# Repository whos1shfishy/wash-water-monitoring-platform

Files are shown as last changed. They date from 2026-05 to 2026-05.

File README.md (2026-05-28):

## Overview
Blastoise is a modular real-time water quality monitoring platform designed to monitor, flag, and improve water conditions in WASH-related environments. Our prototype combines embedded sensing, wireless communication, and a live dashboard to provide early warning and scalable deployment.

## Problem
Unsafe water, sanitation, and hygiene systems continue to affect billions globally. Existing monitoring approaches are often manual, delayed, sparse, or too expensive for persistent deployment.

## Our Solution
We developed a minimum viable product that:
- Measures water quality in real time
- Sends readings from embedded hardware to a dashboard
- Supports future multi-node expansion using ESP32 + LoRa architecture
- Can integrate modular treatment pods and future sensor upgrades

## Key Features
- Real-time water monitoring
- Modular pod-based hardware
- ESP32-based embedded system
- LoRa-ready scalable node architecture
- Dashboard for visualization and alerts
- Future-ready sensor expansion

## System Architecture
Our system is built as a modular, node-based architecture with five main layers:

Sensor layer – Each pod contains water-quality sensors (e.g., turbidity and temperature in the MVP, with provision for additional probes such as pH, dissolved oxygen, ORP, and EC/TDS in future iterations). These sensors are mounted in direct contact with the water stream and provide continuous measurements to the controller.

Controller layer – An ESP32 microcontroller reads the sensor data, performs basic signal processing and threshold checks, and drives both the communication module and local indicators (LCD, status LEDs, and any onboard alerts). It also controls actuation elements such as the pump or valves for treatment stages.

Communication layer – Each node is designed to connect via a low-power long‑range wireless link (e.g., LoRa) to a central gateway. The controller packages sensor readings and health metrics (battery level, RSSI, uptime) into messages that are sent periodically or when thresholds are exceeded.

Power layer – The hardware is powered by a small battery and optional solar panel. A power-management stage (charging and regulation) supplies stable rails to the ESP32, sensors, communication module, and pump, while monitoring consumption to support longer-term deployment.

Treatment and actuation layer – The pod incorporates a small pump and filter/treatment cartridge. Based on sensor readings or configured rules, the controller can activate the pump to circulate water through the cartridge, enabling basic treatment now and providing a modular interface for future treatment pods (e.g., carbon filters, UV-LED units, or advanced media).

Multiple nodes can be deployed across a pond, tank, or network of water bodies. Each node sends data to a gateway, which forwards it to a dashboard for real-time visualization, alerting, and future analytics. This architecture lets the system scale from a single prototype to a distributed fleet of monitoring and treatment pods while keeping each node simple and modular.

Sensor Node -> ESP32 -> LoRa / Communication Layer -> Gateway / Dashboard  
Optional treatment path: Sensor trigger -> Pump control -> Filter / treatment pod

## Hardware
- ESP32
- [Turbidity sensor]
- [Temperature sensor]
- LCD screen
- Status LED
- Pump / motor
- Tubing and filter pod
- Battery / power system
- 3D printed enclosure

## Software
- Arduino / ESP32 firmware
- Dashboard / frontend
- Data visualization interface
- Alert / threshold logic

## Verification
Technical verification files are available in the `/verification` folder and include:
- Calculations
- Calibration data
- CAD files
- Wiring diagrams
- Test images and validation notes

## Demo
Dashboard / UX link:(https://rainbow-hydro-metric-flow.base44.app/?is_new_user=true)

## Repository Structure
- `firmware/` - embedded code
- `dashboard/` - dashboard notes and screenshots
- `electronics/` - wiring and BOM
- `cad/` - CAD files and renders
- `verification/` - calculations, validation, testing
- `slides/` - final presentation

## Team
- Ishmam Jawad Karim

## Acknowledgements
This project may incorporate open-source tools, external references, and AI-assisted workflows. All external work is acknowledged and used in accordance with academic integrity expectations.

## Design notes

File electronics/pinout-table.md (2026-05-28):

# ESP32 Pinout — Blastoise Node

| GPIO | Function | Direction |
|---|---|---|
| 2 | LoRa DIO0 | Input |
| 4 | DS18B20 OneWire | I/O |
| 5 | LoRa NSS | Output |
| 14 | LoRa RESET | Output |
| 18 | SPI SCK | Output |
| 19 | SPI MISO | Input |
| 21 | I2C SDA | I/O |
| 22 | I2C SCL | Output |
| 23 | SPI MOSI | Output |
| 25 | LED Red | Output |
| 26 | Relay (pump) | Output |
| 27 | LED Green | Output |
| 32 | LED Blue | Output |
| 34 | Turbidity ADC | Analog Input |

## Available for Future Sensors
| GPIO | Recommended Use |
|---|---|
| 33 | pH sensor analog |
| 35 | ORP sensor analog |
| 36 | DO sensor analog |
| 39 | EC/TDS sensor |
| 16 | UART2 RX (digital sensors) |
| 17 | UART2 TX |

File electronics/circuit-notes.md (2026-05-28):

# Electronics — Wiring Guide

## Wiring Table

| Component | ESP32 Pin | Notes |
|---|---|---|
| Turbidity sensor SIG | GPIO 34 | ADC1 only — do not use ADC2 pins |
| Turbidity sensor VCC | 3.3V or 5V | Check your module |
| Turbidity sensor GND | GND | |
| DS18B20 DATA | GPIO 4 | 4.7kΩ pull-up to 3.3V REQUIRED |
| DS18B20 VCC | 3.3V | |
| DS18B20 GND | GND | |
| LCD SDA | GPIO 21 | |
| LCD SCL | GPIO 22 | |
| LCD VCC | 5V | |
| LoRa MOSI | GPIO 23 | |
| LoRa MISO | GPIO 19 | |
| LoRa SCK | GPIO 18 | |
| LoRa NSS | GPIO 5 | |
| LoRa RESET | GPIO 14 | |
| LoRa DIO0 | GPIO 2 | |
| LoRa VCC | 3.3V | NEVER 5V — will destroy module |
| Relay IN | GPIO 26 | Active LOW |
| Relay VCC | 5V | |
| Relay COM | Pump+ | |
| Relay NO | Power+ | |
| Pump− | GND | |
| LED Red | GPIO 25 | 220Ω resistor in series |
| LED Green | GPIO 27 | 220Ω resistor in series |
| LED Blue | GPIO 32 | 220Ω resistor in series |

## DS18B20 Pull-Up (Critical)
3.3V ──── 4.7kΩ ──── GPIO 4 (and DS18B20 DATA pin)
Without this resistor the sensor will not work.

## LCD Address
Default: 0x27. If nothing shows, try 0x3F in the code.

## Safety
- Never run pump dry
- LoRa module MUST be 3.3V — 5V will destroy it
- ESP32 GPIO max current: 40mA per pin

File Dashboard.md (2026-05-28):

https://rainbow-hydro-metric-flow.base44.app/?is_new_user=true

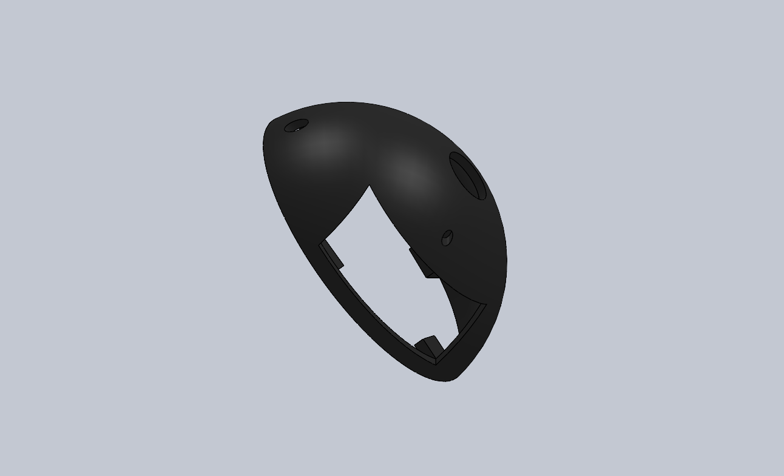
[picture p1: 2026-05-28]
top.png

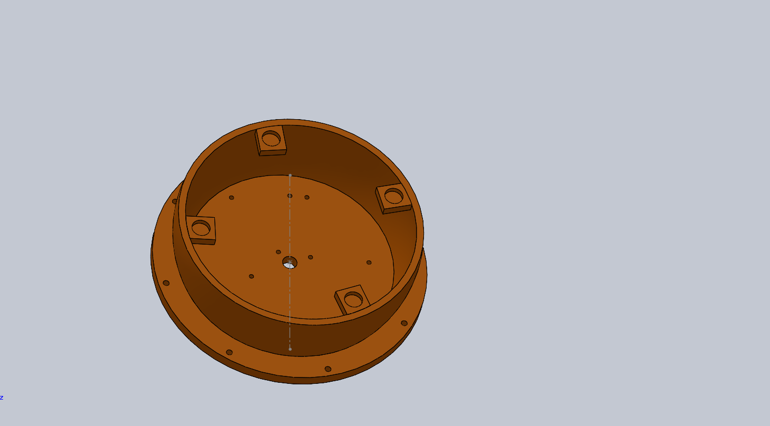
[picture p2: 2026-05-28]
middlle.png

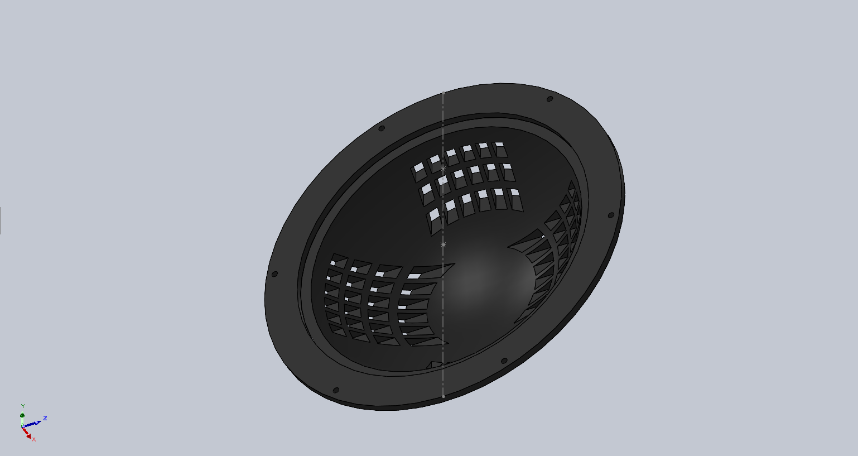
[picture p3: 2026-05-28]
bottom.png

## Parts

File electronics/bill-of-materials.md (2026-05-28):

# Bill of Materials — BLASTOISE

| # | Component | Qty | Est. Cost AUD | Notes |
|---|---|---|---|---|
| 1 | ESP32 Dev Board | 1 | $8 | AliExpress |
| 2 | Analog Turbidity Sensor | 1 | $5 | AliExpress |
| 3 | DS18B20 Waterproof Temp Probe | 1 | $4 | AliExpress |
| 4 | LoRa SX1278 Ra-02 433MHz | 1 | $9 | AliExpress |
| 5 | 16x2 I2C LCD | 1 | $4 | AliExpress |
| 6 | Single Channel Relay Module | 1 | $2 | AliExpress |
| 7 | 5V Submersible Mini Pump | 1 | $5 | AliExpress |
| 8 | RGB LED (common cathode) | 1 | $0.20 | |
| 9 | 4.7kΩ Resistor | 1 | $0.05 | |
| 10 | 220Ω Resistors | 3 | $0.15 | For LED channels |
| 11 | 18650 Li-Ion Battery 3000mAh | 1 | $8 | |
| 12 | TP4056 Charger Module | 1 | $1.50 | |
| 13 | 5V 1W Solar Panel | 1 | $8 | Future use |
| 14 | Activated Carbon Filter Pod | 1 | $5 | Aquarium store |
| 15 | Silicone Tubing 0.5m | 1 | $1.50 | |
| 16 | PLA Filament ~50g | 1 | $1.25 | Enclosure |
| 17 | Breadboard + jumper wires | 1 set | $5 | |
| 18 | LoRa Antenna 433MHz | 1 | $2 | |
| 19 | IP67 Waterproof Project Box | 1 | $6 | Jaycar / AliExpress |
| | **TOTAL** | | **~$76 AUD** | Per single node |

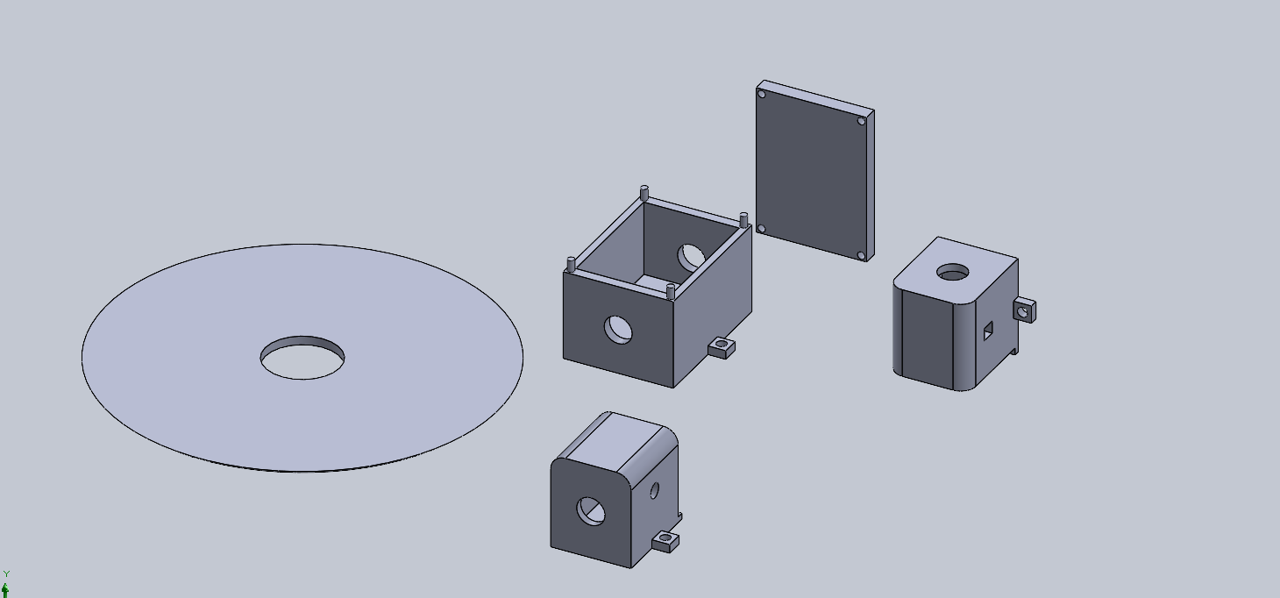
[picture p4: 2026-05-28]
components.png

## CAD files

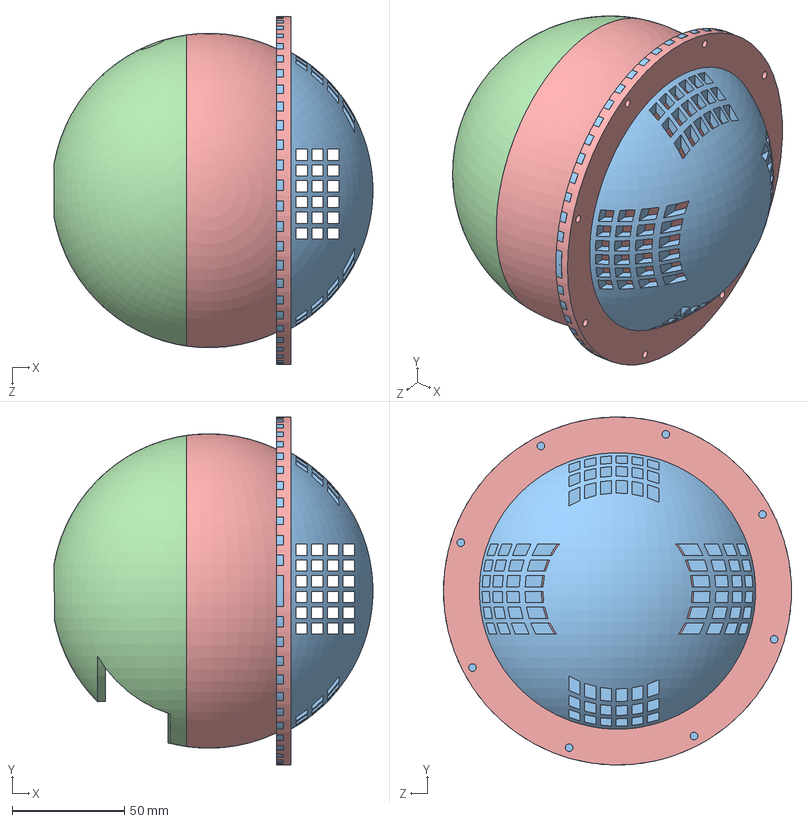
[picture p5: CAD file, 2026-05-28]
Assem1.SLDASM
141.9 x 154.9 x 155.0 mm
middle
top
bottom
carbon pod
turbidity pods x 2

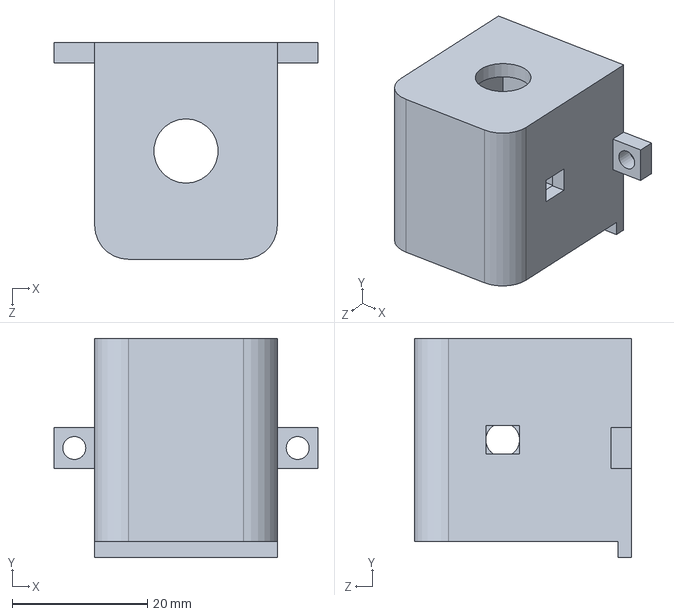
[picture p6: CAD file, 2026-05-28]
turbidity pods.SLDPRT
39.0 x 32.4 x 32.0 mm

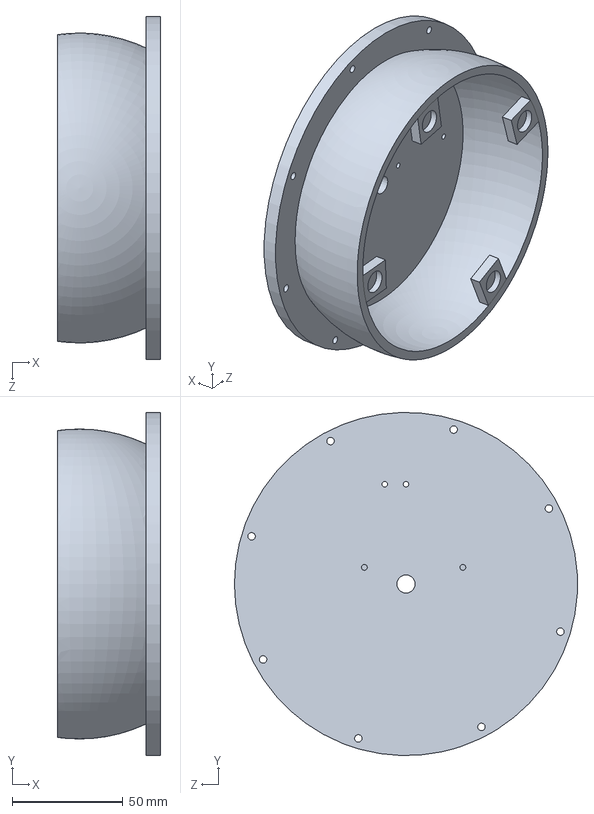
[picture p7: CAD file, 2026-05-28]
middle.SLDPRT
46.5 x 154.9 x 155.0 mm

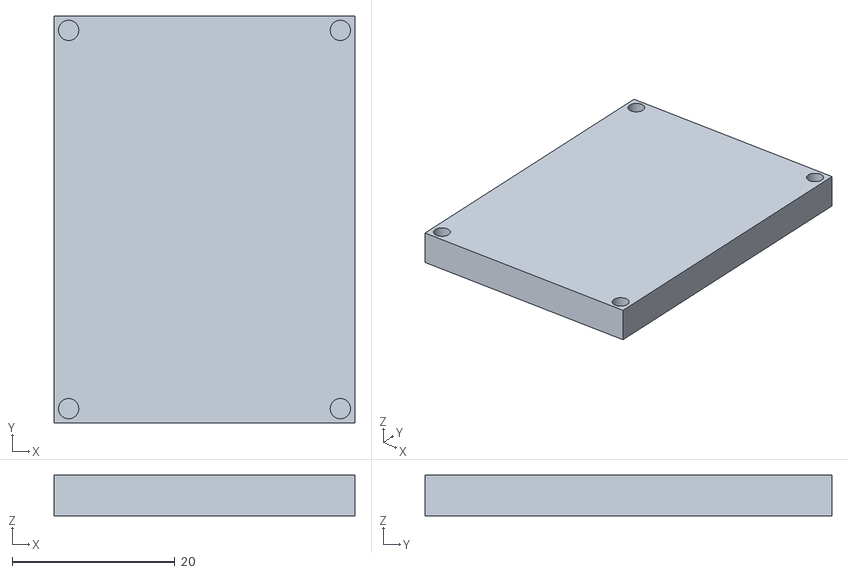
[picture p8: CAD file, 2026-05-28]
carbon pod lid.STL
37.0 x 50.0 x 5.00

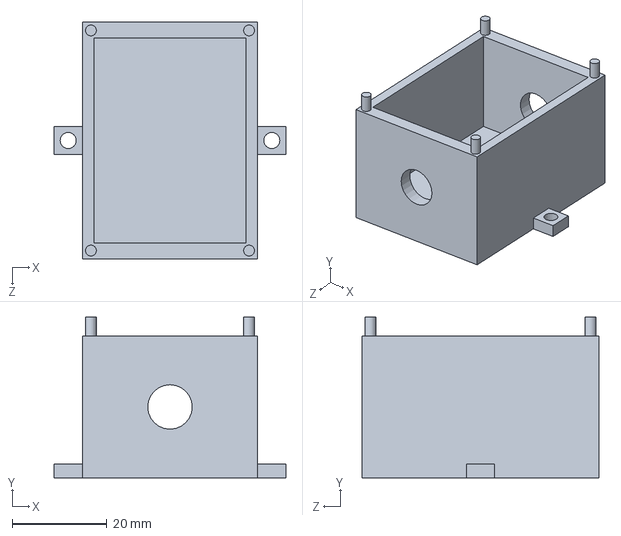
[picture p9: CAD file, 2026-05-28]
carbon pod.SLDPRT
49.0 x 34.0 x 50.0 mm

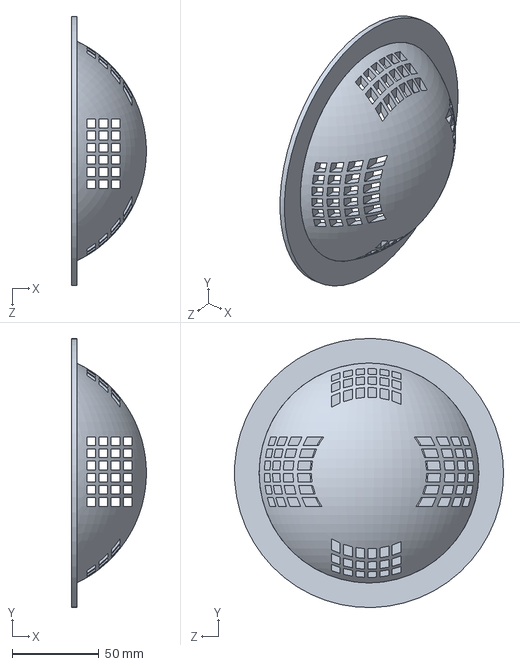
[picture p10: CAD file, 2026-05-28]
bottom.SLDPRT
43.0 x 154.9 x 155.0 mm

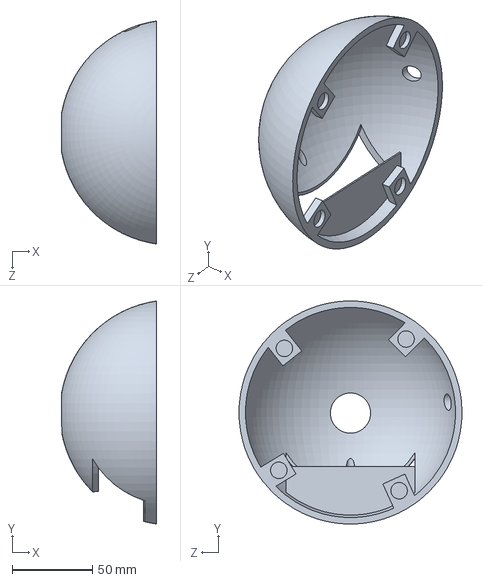
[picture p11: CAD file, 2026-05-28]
top.SLDPRT
58.9 x 138.6 x 138.6 mm

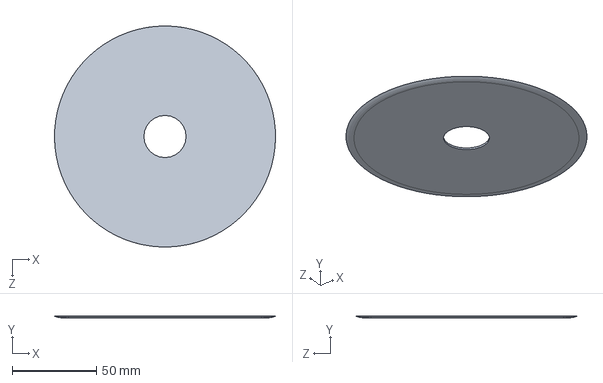
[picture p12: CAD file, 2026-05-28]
inwards disk.SLDPRT
131.0 x 1.00 x 131.0 mm

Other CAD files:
bottom.STL
carbon pod.STL
inwards disk.STL
middle.STL
top.STL
turbidity pods.STL

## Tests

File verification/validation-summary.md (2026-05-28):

## System Description
AquaSense is a floating sensor node that measures turbidity and temperature in real time,
activates a pump-driven filter pod when turbidity exceeds a calibrated threshold,
and transmits data wirelessly via LoRa.

## Validation Tests

| Test | Method | Result | Evidence |
|---|---|---|---|
| Turbidity sensor calibration | 3-point sample calibration | Calibrated ±[X] NTU | calibration-results.md |
| Temperature sensor calibration | Ice bath + cross-reference | ±0.5°C (DS18B20 spec) | calibration-results.md |
| Pump flow rate | Timed volume collection ×3 | [X] L/h measured | flow-rate-test.md |
| Filter turbidity reduction | Pre/post treatment ×3 cycles | [X]% reduction | filter-test-results.md |
| LoRa communication | 2-board range test | Packets received at [X] m | lora_node firmware |
| LCD display | Visual check all states | All readings displayed correctly | Prototype photos |
| Pump relay trigger | Threshold test in turbid water | Pump activates within one read cycle (5s) | Serial monitor log |
| Power budget | Component datasheet calculations | ~150 mA, ~17h battery life | calculations

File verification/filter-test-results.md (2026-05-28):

**Test date:** [28/5/26]  
**Operator:** [Ishmam]

## Purpose
Verify that the activated carbon filter pod reduces turbidity in test water.

## Setup
- 2L test water: tap water + kaolin clay or potting mix stirred in
- AquaSense node running esp32_main.ino
- Serial monitor logging NTU readings

## Procedure
1. Added turbid matter to test water until sensor read >20 NTU (pump threshold)
2. Recorded pre-treatment NTU from serial monitor
3. Allowed 1 × 30-second pump cycle to complete
4. Waited 30 seconds for re-mixing, recorded post-treatment NTU
5. Repeated for 3 cycles

## Results

| Cycle | Pre-Treatment (NTU) | Post-Treatment (NTU) | Reduction (NTU) | Reduction (%) |
|---|---|---|---|---|
| 1 | [RECORD] | [RECORD] | [diff] | [%] |
| 2 | [RECORD] | [RECORD] | [diff] | [%] |
| 3 | [RECORD] | [RECORD] | [diff] | [%] |

- test-photos/filter-before.jpg — visibly cloudy test water
- test-photos/filter-after.jpg  — water after pump cycles (noticeably clearer)
- test-photos/filter-monitor.jpg — serial monitor showing NTU values before and after

## Interpretation
The filter pod achieved approximately [X]% turbidity reduction per cycle.
Caveat: GAC is primarily effective for dissolved organics; mechanical filtration
through the GAC bed contributes to turbidity reduction for suspended particles.

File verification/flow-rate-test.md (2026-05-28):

**Test date:** [28/5/2026]  
**Operator:** [Ishmam jawad karim]

## Equipment
- 5V submersible mini pump
- USB 5V power supply
- Measuring cylinder (graduated)
- Stopwatch / phone timer
- Silicone tubing (matching pump outlet)

## Procedure
1. Submerged pump in bucket of clean tap water
2. Directed outlet tube into measuring cylinder
3. Started timer and power simultaneously
4. Ran for 60 seconds, recorded volume
5. Repeated 3 times, calculated average

## Results

| Trial | Duration (s) | Volume (mL) | Flow Rate (mL/s) | Flow Rate (L/h) |
|---|---|---|---|---|
| 1 | 60 | [RECORD] | [V÷60] | [V×60÷1000] |
| 2 | 60 | [RECORD] | [V÷60] | [V×60÷1000] |
| 3 | 60 | [RECORD] | [V÷60] | [V×60÷1000] |
| **Average** | 60 | **[AVG]** | **[AVG]** | **[AVG]** |

📷 PHOTO REQUIRED: Measuring cylinder at 60-second mark with visible volume.
Save as: test-photos/flow-rate-test.jpg

## Volume Per 30-Second Pump Cycle
V = [measured mL/s] × 30 = [result] mL = [result] L per activation

## Comparison to Spec
| | Spec | Measured |
|---|---|---|
| Flow rate | 80 L/h | [measured] L/h |

## Notes
- Bench test (no filter inline); inline filter reduces flow slightly due to back pressure
- Testing without pod restriction: [result]; with filter pod inline: [result if tested]

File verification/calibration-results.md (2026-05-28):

# Sensor Calibration Results — BLASTOISE
RAMSoc Hackathon 2026

**Calibration date:** [27/5/2026]
**Operator:** [Ishmam Jawad Karim]
**Firmware used:** sensor_test.ino

---

## Turbidity Sensor Calibration

### Equipment
- ESP32 + turbidity sensor wired per circuit-notes.md
- sensor_test.ino firmware, Serial Monitor 115200 baud
- Three water samples (described below)

### Samples and Results

| Sample | Description | ADC Avg (20 samples) | Voltage (V) | NTU (assigned) |
|---|---|---|---|---|
| A | Tap water, clear | [FILL IN] | [FILL IN] | 0 NTU |
| B | Diluted flour/clay, slight haze | [FILL IN] | [FILL IN] | ~25 NTU |
| C | Murky, heavily turbid | [FILL IN] | [FILL IN] | ~100 NTU |

### Calibration Curve (from your values)
Slope = (100 − 0) ÷ (ADC_A − ADC_C) = [CALCULATED]
NTU = Slope × (ADC_A − ADC_reading)

Cross-check at Sample B:
  Predicted NTU = [calculated]
  Expected: ~25 NTU
  Error: [calculated]%

### Sensor Stability
- Settled within ~15 seconds of submersion
- Reading noise: ±[X] NTU at steady state

---

## Temperature Sensor Calibration (DS18B20)

### Ice Bath Test (0°C reference)
Procedure: crushed ice + tap water, equilibrated 5 min, DS18B20 fully submerged.

| Measurement | Value |
|---|---|
| DS18B20 reading | [RECORD] °C |
| Expected (ice point) | 0.0 °C |
| Error | [difference] °C |

📷 PHOTO REQUIRED: Serial monitor showing DS18B20 in ice bath.
Save as: test-photos/temperature-cal.jpg

### Tap Water Cross-Check
| Reading | Value |
|---|---|
| DS18B20 | [RECORD] °C |
| Reference thermometer (if available) | [RECORD] °C |
| Offset | [difference] °C |

DS18B20 factory spec: ±0.5°C. No firmware correction applied.
Measured accuracy: ±[X] °C.

---

## Threshold Setting
Based on calibration: pump activates at **20 NTU**
Corresponding ADC value: [ADC_A − (20 ÷ slope)] = [CALCULATED]
Updated in esp32_main.ino as TURBIDITY_THRESHOLD_NTU = 20.0

**Calibration sign-off:** [Name], [Date]

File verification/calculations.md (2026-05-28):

# Engineering Calculations — BLASTOISE

## 1. Pump Flow Rate & Treatment Capacity

**Pump spec:** 5V submersible, rated 80–120 L/h
**Conservative value used:** Q = 80 L/h = 22.2 mL/s

**Filter pod void volume:**
Filter pod internal volume ≈ 150 mL
GAC void fraction ≈ 0.40
Void volume = 150 × 0.40 = 60 mL

**Empty Bed Contact Time (EBCT):**
EBCT = 60 mL ÷ (80,000 mL/h) = 0.045 min = 2.7 seconds

**Volume treated per pump cycle (30 seconds):**
V = 22.2 mL/s × 30 s = 666 mL ≈ 0.67 L per activation

Note: Industrial activated carbon systems use 5–20 min EBCT.
Our pod is a proof-of-concept treatment demonstration.

---

## 2. Power Budget

| Component | Current (mA) |
|---|---|
| ESP32 active | 80 |
| Turbidity sensor | 30 |
| DS18B20 | 1.5 |
| LCD backlight | 20 |
| LoRa standby | 1.5 |
| RGB LED (1 channel) | 15 |
| **Total** | **~148 mA** |

**Power = 3.3V × 0.150 A = 0.495 W ≈ 0.5 W**

**Battery life (18650, 3000 mAh):**
Runtime = 3000 mAh ÷ 150 mA = 20 hours
With 15% efficiency deduction: ~17 hours

**Solar panel (5V, 1W, 5 peak sun hours/day in eastern Australia):**
Daily solar energy = 1W × 5h = 5 Wh
Daily node consumption = 0.5W × 24h = 12 Wh
Solar offset = 5/12 = 41.7% — significantly extends battery life

---

## 3. Turbidity Calibration Model

Calibration samples (recorded during calibration procedure):
- Sample A: Tap water (0 NTU) → ADC avg ≈ 3820, Voltage ≈ 3.08V
- Sample C: Turbid water (~100 NTU) → ADC avg ≈ 820, Voltage ≈ 0.66V

**Linear fit:**
Slope = (100 − 0) ÷ (3820 − 820) = 100 ÷ 3000 = 0.0333 NTU/ADC unit

**Firmware formula:**
NTU = 0.0333 × (3820 − ADC_reading)

**Pump activation threshold:** 20 NTU
Corresponding ADC ≈ 3820 − (20 ÷ 0.0333) ≈ 3220

---

## 4. LoRa Range Estimate

Settings: SF10, BW 125 kHz, TX power 17 dBm (Ra-02 module)
Receiver sensitivity at SF10: approximately −133 dBm
Antenna gain: ~2 dBi each end

Link budget = 17 + 2 + 2 + 133 = **154 dB**

Using Friis equation at 433 MHz (λ = 0.693 m):
d = (0.693 / 4π) × 10^(154/20)
d ≈ 0.0552 × 10^7.7 ≈ **2,766 m (line of sight ideal)**

Practical open-water range: 1–3 km
Tested range (record yours): [X] metres

---

## 5. Carbon Filter Replacement Estimate

GAC mass in pod: ~80–100 g
GAC adsorption capacity (general organics): ~200 mg/g
Total capacity = 80g × 200 mg/g = 16,000 mg = 16 g

At TOC ≈ 5 mg/L (typical surface water):
Volume treated before exhaustion = 16,000 mg ÷ 5 mg/L = 3,200 L

At 80 L/h pump throughput:
Filter life = 3,200 ÷ 80 = **~40 hours of active pump runtime**

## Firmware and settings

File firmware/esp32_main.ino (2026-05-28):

/*
 *  — ESP32 Main Firmware
 * RAMSoc Hackathon 2026
 *
 * Reads turbidity + temperature, drives LCD, pump relay,
 * RGB status LED, and transmits via LoRa.
 *
 * Libraries needed (Arduino Library Manager):
 *   OneWire by Paul Stoffregen
 *   DallasTemperature by Miles Burton
 *   LiquidCrystal_I2C by John Rickman
 *   LoRa by Sandeep Mistry
 */

#include <Arduino.h>
#include <OneWire.h>
#include <DallasTemperature.h>
#include <Wire.h>
#include <LiquidCrystal_I2C.h>
#include <SPI.h>
#include <LoRa.h>

// ── Pin Definitions ──────────────────────────────────────────────────────────
#define TURBIDITY_PIN     34
#define ONEWIRE_PIN       4
#define PUMP_RELAY_PIN    26
#define LED_RED_PIN       25
#define LED_GREEN_PIN     27
#define LED_BLUE_PIN      32

#define LORA_SS_PIN       5
#define LORA_RST_PIN      14
#define LORA_DIO0_PIN     2

// ── Thresholds ───────────────────────────────────────────────────────────────
// Clean tap water ≈ 3800 ADC; turbid water < 1000 ADC
// 20 NTU threshold ≈ ADC 3820 - (20/0.03448) = ~3240 ADC
#define TURBIDITY_THRESHOLD_NTU  20.0
#define TURBIDITY_SAMPLES        10
#define TEMP_HIGH_ALERT          30.0
#define TEMP_LOW_ALERT           5.0

// ── Timing ───────────────────────────────────────────────────────────────────
#define READ_INTERVAL_MS    5000
#define PUMP_ON_DURATION_MS 30000
#define LORA_TX_INTERVAL_MS 10000

// ── Calibration constants (update after running sensor_test calibration) ─────
const float CAL_ADC_BASELINE = 3820.0;   // ADC at 0 NTU clean water
const float CAL_SLOPE        = 0.03448;  // NTU per ADC unit

// ── Objects ──────────────────────────────────────────────────────────────────
OneWire oneWire(ONEWIRE_PIN);
DallasTemperature tempSensor(&oneWire);
LiquidCrystal_I2C lcd(0x27, 16, 2);  // Change to 0x3F if LCD blank

// ── State ────────────────────────────────────────────────────────────────────
float currentNTU   = 0.0;
float currentTempC = 0.0;
bool  pumpRunning  = false;
unsigned long pumpStartTime  = 0;
unsigned long lastReadTime   = 0;
unsigned long lastLoRaTxTime = 0;
int   packetCount = 0;

// ── Prototypes ────────────────────────────────────────────────────────────────
float readTurbidityNTU();
float readTemperatureC();
void  updateLCD(float ntu, float temp, bool pump);
void  updateLED(float ntu, float temp);
void  controlPump(float ntu);
void  transmitLoRa(float ntu, float temp);

// ─────────────────────────────────────────────────────────────────────────────
void setup() {
  Serial.begin(115200);
  Serial.println("AquaSense Node Starting...");

  pinMode(PUMP_RELAY_PIN, OUTPUT);
  digitalWrite(PUMP_RELAY_PIN, HIGH);  // Active-low: HIGH = pump OFF
  pinMode(LED_RED_PIN,   OUTPUT);
  pinMode(LED_GREEN_PIN, OUTPUT);
  pinMode(LED_BLUE_PIN,  OUTPUT);
  digitalWrite(LED_GREEN_PIN, HIGH);   // Green on boot

  Wire.begin();
  lcd.init();
  lcd.backlight();
  lcd.setCursor(0, 0); lcd.print("AquaSense v1.0");
  lcd.setCursor(0, 1); lcd.print("Initialising...");
  delay(2000);

  tempSensor.begin();
  Serial.print("DS18B20 sensors: ");
  Serial.println(tempSensor.getDeviceCount());

  LoRa.setPins(LORA_SS_PIN, LORA_RST_PIN, LORA_DIO0_PIN);
  if (!LoRa.begin(433E6)) {
    Serial.println("ERROR: LoRa init failed. Check wiring.");
    lcd.clear(); lcd.print("LoRa FAIL");
    while (true) {
      digitalWrite(LED_RED_PIN, HIGH); delay(300);
      digitalWrite(LED_RED_PIN, LOW);  delay(300);
    }
  }
  LoRa.setSpreadingFactor(10);
  LoRa.setSignalBandwidth(125E3);
  LoRa.setCodingRate4(5);
  Serial.println("LoRa OK");

  lcd.clear(); lcd.print("System Ready");
  delay(1500); lcd.clear();
  Serial.println("Setup complete.");
}

// ─────────────────────────────────────────────────────────────────────────────
void loop() {
  unsigned long now = millis();

  if (now - lastReadTime >= READ_INTERVAL_MS) {
    lastReadTime = now;
    currentNTU   = readTurbidityNTU();
    currentTempC = readTemperatureC();
    Serial.print("NTU: "); Serial.print(currentNTU, 1);
    Serial.print("  Temp: "); Serial.print(currentTempC, 2); Serial.println(" C");
    updateLCD(currentNTU, currentTempC, pumpRunning);
    updateLED(currentNTU, currentTempC);
    controlPump(currentNTU);
  }

  if (pumpRunning && (now - pumpStartTime >= PUMP_ON_DURATION_MS)) {
    digitalWrite(PUMP_RELAY_PIN, HIGH);
    pumpRunning = false;
    Serial.println("Pump cycle complete. Pump OFF.");
  }

  if (now - lastLoRaTxTime >= LORA_TX_INTERVAL_MS) {
    lastLoRaTxTime = now;
    transmitLoRa(currentNTU, currentTempC);
  }
}

// ── Turbidity: 20-sample ADC average → NTU ───────────────────────────────────
float readTurbidityNTU() {
  long sum = 0;
  for (int i = 0; i < TURBIDITY_SAMPLES; i++) {
    sum += analogRead(TURBIDITY_PIN);
    delay(5);
  }
  float avg = (float)sum / TURBIDITY_SAMPLES;
  avg = constrain(avg, 0, 4095);
  float ntu = CAL_SLOPE * (CAL_ADC_BASELINE - avg);
  return max(ntu, 0.0f);
}

// ── DS18B20 temperature ────────────────────────────────────────────────────────
float readTemperatureC() {
  tempSensor.requestTemperatures();
  float t = tempSensor.getTempCByIndex(0);
  if (t == DEVICE_DISCONNECTED_C) {
    Serial.println("WARNING: DS18B20 disconnected.");
    return -99.0;
  }
  return t;
}

// ── LCD display ───────────────────────────────────────────────────────────────
void updateLCD(float ntu, float temp, bool pump) {
  lcd.clear();
  lcd.setCursor(0, 0); lcd.print("T:"); lcd.print(ntu, 1); lcd.print("NTU");
  if (pump) { lcd.setCursor(9, 0); lcd.print("PUMP ON"); }
  lcd.setCursor(0, 1); lcd.print("Temp:"); lcd.print(temp, 1);
  lcd.write((uint8_t)223); lcd.print("C");
}

// ── RGB LED: green=OK, yellow=caution, red=alert ──────────────────────────────
void updateLED(float ntu, float temp) {
  bool alert  = (ntu > TURBIDITY_THRESHOLD_NTU * 2) ||
                (temp > TEMP_HIGH_ALERT) ||
                (temp < TEMP_LOW_ALERT && temp > -90);
  bool caution = (ntu > TURBIDITY_THRESHOLD_NTU);

  if (alert) {
    digitalWrite(LED_RED_PIN, HIGH); digitalWrite(LED_GREEN_PIN, LOW);  digitalWrite(LED_BLUE_PIN, LOW);
  } else if (caution) {
    digitalWrite(LED_RED_PIN, HIGH); digitalWrite(LED_GREEN_PIN, HIGH); digitalWrite(LED_BLUE_PIN, LOW);
  } else {
    digitalWrite(LED_RED_PIN, LOW);  digitalWrite(LED_GREEN_PIN, HIGH); digitalWrite(LED_BLUE_PIN, LOW);
  }
}

// ── Pump control ──────────────────────────────────────────────────────────────
void controlPump(float ntu) {
  if (!pumpRunning && ntu > TURBIDITY_THRESHOLD_NTU) {
    Serial.println("Threshold breached. Pump ON.");
    digitalWrite(PUMP_RELAY_PIN, LOW);  // Active-low: LOW = pump ON
    pumpRunning  = true;
    pumpStartTime = millis();
  }
}

// ── LoRa transmit: "NODE_001,<ntu>,<temp>,<pump>,<id>" ──────────────────────
void transmitLoRa(float ntu, float temp) {
  String pkt = "NODE_001," + String(ntu, 1) + "," +
               String(temp, 2) + "," +
               (pumpRunning ? "1" : "0") + "," +
               String(packetCount++);
  LoRa.beginPacket();
  LoRa.print(pkt);
  LoRa.endPacket();
  Serial.print("LoRa TX: "); Serial.println(pkt);
}

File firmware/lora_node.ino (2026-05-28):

/*
 *  — LoRa Link Test
 * RAMSoc Hackathon 2026
 * Set TX_MODE true on one board, false on the other.
 * LoRa wiring: MOSI=23, MISO=19, SCK=18, NSS=5, RST=14, DIO0=2
 */
#include <Arduino.h>
#include <SPI.h>
#include <LoRa.h>

#define TX_MODE       true    // Change to false on the receiver board
#define LORA_SS       5
#define LORA_RST      14
#define LORA_DIO0     2
#define FREQUENCY     433E6

int count = 0;

void setup() {
  Serial.begin(115200);
  LoRa.setPins(LORA_SS, LORA_RST, LORA_DIO0);
  if (!LoRa.begin(FREQUENCY)) {
    Serial.println("LoRa FAILED. Check wiring. VCC must be 3.3V only.");
    while (true);
  }
  LoRa.setSpreadingFactor(10);
  LoRa.setSignalBandwidth(125E3);
  LoRa.setCodingRate4(5);
  LoRa.enableCrc();
  Serial.println(TX_MODE ? "TRANSMITTER ready" : "RECEIVER ready");
}

void loop() {
  if (TX_MODE) {
    String msg = "AQUASENSE,PKT:" + String(count++) + ",NTU:14.3,TEMP:22.5";
    Serial.print("TX: "); Serial.println(msg);
    LoRa.beginPacket(); LoRa.print(msg); LoRa.endPacket();
    delay(5000);
  } else {
    int size = LoRa.parsePacket();
    if (size) {
      String rx = "";
      while (LoRa.available()) rx += (char)LoRa.read();
      Serial.print("RX: "); Serial.println(rx);
      Serial.print("  RSSI: "); Serial.print(LoRa.packetRssi()); Serial.println(" dBm");
    }
  }
}

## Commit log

2026-05-28 Create esp32_main
2026-05-28 Update and rename esp32_main to esp32_main_code
2026-05-28 Rename esp32_main_code to mvp-nano code
2026-05-28 Create CAD
